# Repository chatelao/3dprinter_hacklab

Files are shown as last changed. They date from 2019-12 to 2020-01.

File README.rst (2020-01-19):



.. readme-header-marker-do-not-remove

Unser 3D Drucker im Hacklab Bern
################################

Anleitung zum Drucken
~~~~~~~~~~~~~~~~~~~~~

Der 3D Drucker im **Hacklab Bern** (https://www.meetup.com/de-DE/Bern-Silicon-Valley-HackLab-Tech-Group),
basiert auf dem `CL-260 <https://www.thingiverse.com/groups/cl-260/things>`_ 
open-source `Model <https://www.thingiverse.com/minicooper/collections/cl-260>`_.
Er wird abwechslungsweise von Mitgliedern genutzt und verbessert.

Slicer Software für PC/Mac
==========================

Für das Erstellen der Druckbefehle aus den (.stl) 3D-Modellen wird zwingend ein *Slicer* Programm
benötigt. Der grosse Klassiker ist *Cura*, die Alternativen wie *Prusa-Slicer* funktionieren sehr
ähnlich:

+-------------------------------------------------------+---------------+-------------------+
|                       Software                        |     Zweck     | Chocolately Paket |
+=======================================================+===============+===================+
| Cura                                                  | Slicer        | cura-new          |
+-------------------------------------------------------+---------------+-------------------+
| `Prusa Slicer <https://www.prusa3d.com/prusaslicer>`_ | Slicer        | prusaslicer       |
+-------------------------------------------------------+---------------+-------------------+

Der Slicer muss gewisse Details des Druckers kennen, damit er ihn gut ansteuern kann. Anbei 
einige bewährte, wesentliche Einstellungen:

+--------------------+----------------------------------+
|    Einstellung     |         Empfohlener Wert         |
+====================+==================================+
| Drucker Art        | FFF (Fused Filament Fabrication) |
+--------------------+----------------------------------+
| Druckauflösung     | 0.15mm                           |
+--------------------+----------------------------------+
| Retraction         | **5mm**                          |
+--------------------+----------------------------------+
| PLA Druckkopf      | 210°C (erste Schicht) / 200°C    |
+--------------------+----------------------------------+
| PLA Heizbett       | 55°C (erste Schicht) / 50°C      |
+--------------------+----------------------------------+

Software zur Fernsteuerung
==========================

Die Steuerung und Statuskontrolle des Druckers geht viel einfacher mit `OctoPrint <https://octoprint.org/download/>`_  auf einem RaspberryPi. Damit lassen sich Durckdateien bequem hochladen und der Status jederzeit abfragen. Noch mehr Komfort bieten Plug-Ins wie:

- `Telegram Integration <https://github.com/fabianonline/OctoPrint-Telegram>`_
- `Fortschrittsanzeige auf dem Drucker <https://github.com/OllisGit/OctoPrint-DisplayLayerProgress>`_

Filamente
=========

Kein Druck ohne Filamente, diese können hier bezogen werden:

- Im FabLab Bern: https://www.objektweberei.ch
- Online u.a. bei 3D-Jake: https://www.3djake.ch/de-CH/filament/pla-filament

Anleitung zum Warten
~~~~~~~~~~~~~~~~~~~~

Bed leveling
============

- Autohome
- Z-Axes senken
- Differenz an am Z-Stopp nachschrauen
- Alle Vier Ecken nachprüfen

Nozzle reinigen
===============

- https://www.youtube.com/watch?v=g8uvh6kvr54
- **Cold pull** das Hotend auf 120°C anwärmen und laufend ziehen, bis das Verstopfte herauskommen.

Wartungssoftware
================

Zur Wartung des Druckers hilft *Pronterface*, es stellt die technischeren Schnittstellen, wie
das serielle Terminal zur direkten Kommunikation mit dem Drucker und bequeme Kontrolleknöpfe
zum Bewegen der Achsen zur Verfügung.

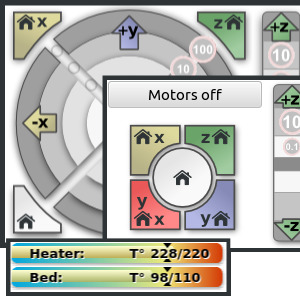
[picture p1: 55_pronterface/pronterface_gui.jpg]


+-------------------------------------------------------+---------------+-------------------+
|                       Software                        |     Zweck     | Chocolately Paket |
+=======================================================+===============+===================+
| `Pronterface <https://www.pronterface.com/>`_         | Fernsteuerung | printrun          |
+-------------------------------------------------------+---------------+-------------------+

Hardware & Werkzeug
===================

- Akkupunkturnadeln
- 2.5mm Imbusschlüssel
- 7mm Innen Sechskantschlüssel
- Messingbürste
- Flachzange
- Seitenschneider
- 1.3mm Imbusschlüssel
- M3 Schrauben und Muttern
- 5er Gabelschlüssel
- Isopropanol
- Haushaltspapier
- Schieblehre
- Kaptontape

Fehlersuche
===========

Die Fehlersuche am Drucker ist mühsam, allerdings bietet Pursa ein Handbuch
zum Erkennen der gängigsten Fehler:

- https://www.prusa3d.com/print-quality-troubleshooting/

Dazu hat auch der 3D-Andi ein hervorragendes Video mit vielen Fehlerquellen und -lösungen gedreht:

- https://www.youtube.com/watch?v=WL3T_ijUUs8

Düse montieren
==============

Bei der Montage der Düse ist sicherzustellen, dass die Düse kalt nur 0.7mm vor dem Limit angezogen ist.
In warmem Zustand kann die Düse zusätzlich nach ajustiert werden.

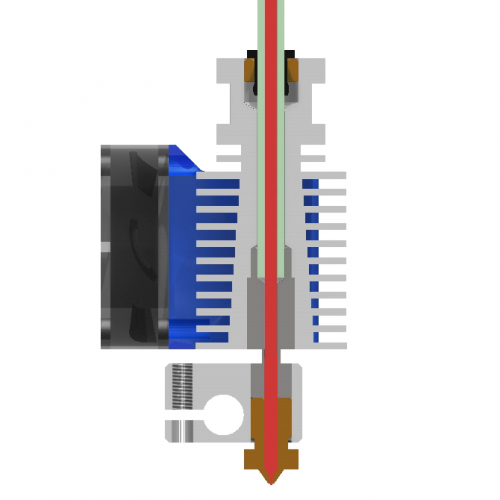
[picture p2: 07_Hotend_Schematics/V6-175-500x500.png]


- https://youtu.be/OzRAVkXjw3I

Kalibrationsmuster
==================

Zur Prüfung der Ausrichtung des Heizbetts eignen sich dieses speziellen Quadratmuster. Es erlaubt die Prüfung
der Druckhöhe und der Distanz zwischen Hotend und Heizbetts.

- Video: https://youtu.be/RZRY6kunAvs
- Quelle: https://www.thingiverse.com/thing:2789086
- STL: `calibration_patterns <https://github.com/chatelao/3dprinter_hacklab/tree/master/calibration_patterns>`_

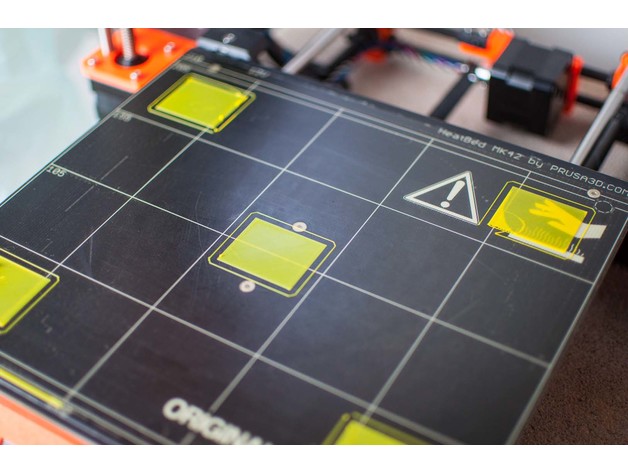
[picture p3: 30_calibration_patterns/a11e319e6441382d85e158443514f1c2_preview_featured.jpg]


Weitere Kalibrierungsmuster:
- https://www.youtube.com/watch?v=kgCjDy_IgXg

Support Forum
=============

- https://www.3d-druck-community.de/

Aktueller Aufbau
################

Die Mitglieder verbessern den Aufbau des Druckers laufend. Aktuell setzt er sich aus folgenden Bestandteilen zusammen:

+---------------------------------------------------------+--------------------------------------------------------------------------------------------------------------+
|                     Funktionalität                      |                                                    Verwendete Lösung                                         |
+=========================================================+==============================================================================================================+
| Firmware                                                | `Marlin 2.0.x <https://github.com/MarlinFirmware/Marlin>`_                                                   |
+---------------------------------------------------------+--------------------------------------------------------------------------------------------------------------+
| Mikrocontroller                                         | `Arduino Mega 2560 <https://www.3dware.ch/Iduino-MEGA2560-De.htm>`_                                          |
+---------------------------------------------------------+--------------------------------------------------------------------------------------------------------------+
| Leistungselektronik Shield                              | `RepRap-Arduino-Mega-Pololu-Shield (RAMPS) 1.4 <https://reprap.org/wiki/RAMPS_1.4>`_                         |
+---------------------------------------------------------+--------------------------------------------------------------------------------------------------------------+
| Verstärker Schrittmotoren                               | `A4988 Datasheet <https://www.allegromicro.com/~/media/Files/Datasheets/A4988-Datasheet.ashx>`_              |
+---------------------------------------------------------+--------------------------------------------------------------------------------------------------------------+
| Display Platine                                         | `RepRapdiscount smart controller 2004 LCD (RED) <https://reprap.org/wiki/RepRapDiscount_Smart_Controller>`_  |
+---------------------------------------------------------+--------------------------------------------------------------------------------------------------------------+
| Schrittmotoren                                          | NEMA ?                                                                                                       |
+---------------------------------------------------------+--------------------------------------------------------------------------------------------------------------+
| Zahnriemen                                              | 5mm breit, 2mm Zahnschritt                                                                                   |
+---------------------------------------------------------+--------------------------------------------------------------------------------------------------------------+
| Antriebsstangen                                         | 8mm Stahlstangen                                                                                             |
+---------------------------------------------------------+--------------------------------------------------------------------------------------------------------------+
| Lager der Antriebsstangen                               | 8 mm (innen) / 22 mm (aussen) / 7 mmm (Dicke) Standardlager                                                  |
+---------------------------------------------------------+--------------------------------------------------------------------------------------------------------------+
| Pulley                                                  | 20 Zähne, 8mm Innendurchmesser, mit M3 Imbusfixierung                                                        |
+---------------------------------------------------------+--------------------------------------------------------------------------------------------------------------+
| Heat Bed                                                |                                                                                                              |
+---------------------------------------------------------+--------------------------------------------------------------------------------------------------------------+
| Bowden Schlauch                                         | `2mm PTFE Tube <https://www.aliexpress.com/item/4000266365536.html>`_                                        |
+---------------------------------------------------------+--------------------------------------------------------------------------------------------------------------+
| Bowden Start (Motor, M5)                                | `PC4-M5 <https://www.aliexpress.com/item/4000182529332.html>`_                                               |
+---------------------------------------------------------+--------------------------------------------------------------------------------------------------------------+
| Bowden Ende (Heizkopf, R1/8)                            | `PC4-01 <https://www.aliexpress.com/item/4000182529332.html>`_                                               |
+---------------------------------------------------------+--------------------------------------------------------------------------------------------------------------+
| Hot End                                                 | Hotend: e3d v6                                                                                               |
+---------------------------------------------------------+--------------------------------------------------------------------------------------------------------------+
| Nozzle                                                  | 0.4mm                                                                                                        |
+---------------------------------------------------------+--------------------------------------------------------------------------------------------------------------+
| `3D Teile <https://www.thingiverse.com/thing:1800495>`_ | Gedruckte Teile                                                                                              |
+---------------------------------------------------------+--------------------------------------------------------------------------------------------------------------+
| Stromversorgung                                         | Schaltnetzteil 12V 20A ohne aktive Kühlung                                                                   |
+---------------------------------------------------------+--------------------------------------------------------------------------------------------------------------+
| Medium                                                  | SD-Karte, regulärer Grösse                                                                                   |
+---------------------------------------------------------+--------------------------------------------------------------------------------------------------------------+
| Datenkabel                                              | USB-Kabel mit Standard-B Stecker den Mikrocontroller                                                         |
+---------------------------------------------------------+--------------------------------------------------------------------------------------------------------------+

Marlin Konfiguration
~~~~~~~~~~~~~~~~~~~~

Mit der Pronterface_ Software kann der Drucker über `gCode Befehle <http://marlinfw.org/docs/gcode/M115.html>`_ oder das GUI mit der seriellen Schnittstelle ferngesteuert und untersucht werden:

M115 - Firmware Informations
============================

::

   >>> M115
   SENDING:M115
   FIRMWARE_NAME:Marlin 2.0.x (GitHub)
   SOURCE_CODE_URL:https://github.com/MarlinFirmware/Marlin
   PROTOCOL_VERSION:1.0
   MACHINE_TYPE:Hacklab CL260 
   EXTRUDER_COUNT:1 
   UUID:b01ac89d-d7b3-43ec-8f82-dfb65c785486
   
   Cap:SERIAL_XON_XOFF:0
   Cap:BINARY_FILE_TRANSFER:0
   Cap:EEPROM:0
   Cap:VOLUMETRIC:1
   Cap:AUTOREPORT_TEMP:1
   Cap:PROGRESS:0
   Cap:PRINT_JOB:1
   Cap:AUTOLEVEL:0
   Cap:Z_PROBE:0
   Cap:LEVELING_DATA:0
   Cap:BUILD_PERCENT:0
   Cap:SOFTWARE_POWER:0
   Cap:TOGGLE_LIGHTS:0
   Cap:CASE_LIGHT_BRIGHTNESS:0
   Cap:EMERGENCY_PARSER:0
   Cap:PROMPT_SUPPORT:0
   Cap:AUTOREPORT_SD_STATUS:0

M503 - Report Settings (Marlin 2.0.x)
=====================================

+--------------------------------+----------------------------------------------------+--------------+
|          Einstellung           | gCode                                              | Marlin 2.0.x |
+================================+====================================================+==============+
| Units in mm (mm)               | `G21 <http://marlinfw.org/docs/gcode/G021.html>`_  |              |
+--------------------------------+----------------------------------------------------+--------------+
| Filament diameter              | `M200 <http://marlinfw.org/docs/gcode/M200.html>`_ | D1.75        |
+--------------------------------+----------------------------------------------------+--------------+
| Steps per unit                 | `M92 <http://marlinfw.org/docs/gcode/M92.html>`_   | X80.00       |
|                                |                                                    +--------------+
|                                |                                                    | Y80.00       |
|                                |                                                    +--------------+
|                                |                                                    | Z1600.00     |
|                                |                                                    +--------------+
|                                |                                                    | E161.00      |
+--------------------------------+----------------------------------------------------+--------------+
| Max. Speed (mm/s)              | `M203 <http://marlinfw.org/docs/gcode/M203.html>`_ | X300.00      |
|                                |                                                    +--------------+
|                                |                                                    | Y300.00      |
|                                |                                                    +--------------+
|                                |                                                    | Z5.00        |
|                                |                                                    +--------------+
|                                |                                                    | E45.00       |
+--------------------------------+----------------------------------------------------+--------------+
| Max. Acceleration (mm/s2)      | `M201 <http://marlinfw.org/docs/gcode/M201.html>`_ | X9000        |
|                                |                                                    +--------------+
|                                |                                                    | Y9000        |
|                                |                                                    +--------------+
|                                |                                                    | Z100         |
|                                |                                                    +--------------+
|                                |                                                    | E10000       |
+--------------------------------+----------------------------------------------------+--------------+
| S=Acceleration                 | `M204 <http://marlinfw.org/docs/gcode/M204.html>`_ |              |
+--------------------------------+                                                    +--------------+
| P=Print Acceleration (mm/s2)   |                                                    | P3000.00     |
+--------------------------------+                                                    +--------------+
| R=Retract Acceleration (mm/s2) |                                                    | R3000.00     |
+--------------------------------+                                                    +--------------+
| T=Retract Acceleration (mm/s2) |                                                    |              |
+--------------------------------+                                                    +--------------+
| T=Travel Acceleration (mm/s2)  |                                                    | T3000.00     |
+--------------------------------+----------------------------------------------------+--------------+
| B=minimum segment time (ms)    | `M205 <http://marlinfw.org/docs/gcode/M205.html>`_ | B20000       |
+--------------------------------+                                                    +--------------+
| S=Min feedrate (mm/s)          |                                                    | S0.00        |
+--------------------------------+                                                    +--------------+
| T=Min travel feedrate (mm/s)   |                                                    | T0.00        |
+--------------------------------+                                                    +--------------+
| J=Junc_dev                     |                                                    | J0.01        |
+--------------------------------+----------------------------------------------------+--------------+
| Home offset (mm)               | `M206 <http://marlinfw.org/docs/gcode/M206.html>`_ | X0.00        |
|                                |                                                    | Y0.00        |
|                                |                                                    | Z0.00        |
+--------------------------------+----------------------------------------------------+--------------+
| Hotend PID settings            | `M301 <http://marlinfw.org/docs/gcode/M301.html>`_ | P22.20       |
|                                |                                                    +--------------+
|                                |                                                    | I1.08        |
|                                |                                                    +--------------+
|                                |                                                    | D114.00      |
+--------------------------------+----------------------------------------------------+--------------+

Der RepRap Shield
~~~~~~~~~~~~~~~~~

Das **RepRap Arduino Mega Pololu Shield** dient als Plattform zur Anbindung
aller weiteren Eletronik am System:

1. Dem *Arduino Mega* als Microkontroller
2. Den Schrittmotoren, ihren Reglern und Endsensoren
3. Dem Heizkopf und -bett, sowie ihren jeweiligen Messfühlern
4. Dem LCD-Display und Drehtaster mit SD-Kartenleser
5. Den Lüftern für den Heizkopf und das Material
6. etc.

Die Stecker und Verkabelungen
=============================

RAMPS 1.4 wiring schematics

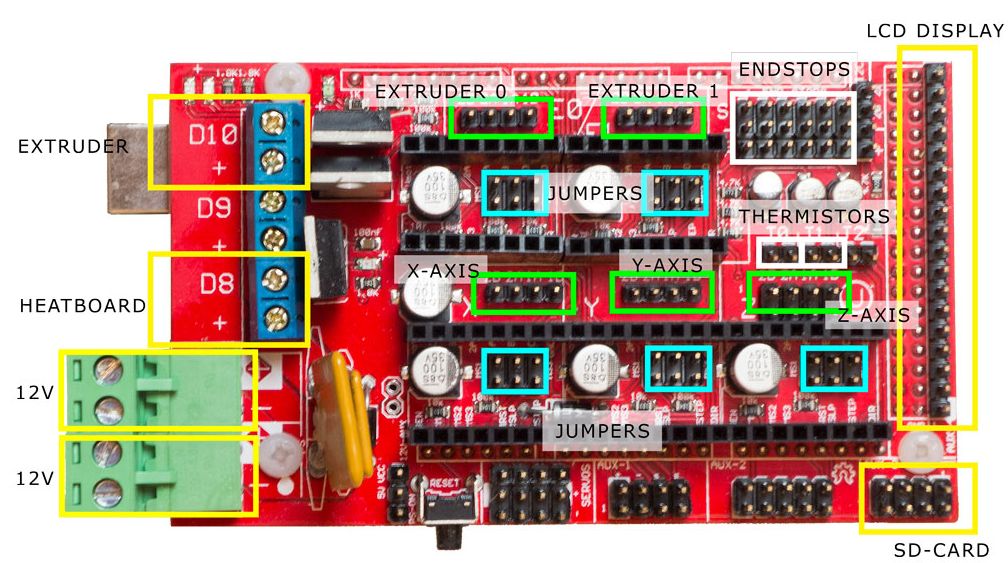
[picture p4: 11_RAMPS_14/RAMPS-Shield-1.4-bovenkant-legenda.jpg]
RAMPS 1.4 photo with pinout legend


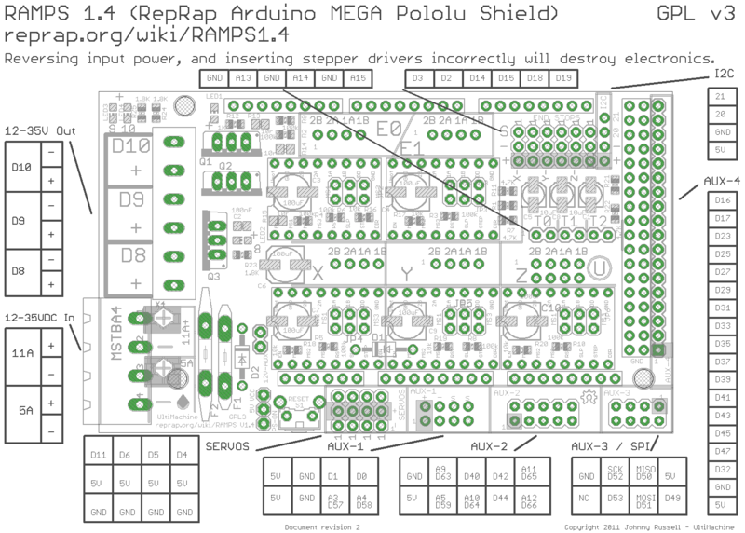
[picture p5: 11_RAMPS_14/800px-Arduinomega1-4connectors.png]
RAMPS 1.4 pinouts schematics


Das elektronische Schema
========================

RAMPS 1.4 electronic schematics


Der LCD-Display mit Taster & SD-Kartenlesen
~~~~~~~~~~~~~~~~~~~~~~~~~~~~~~~~~~~~~~~~~~~

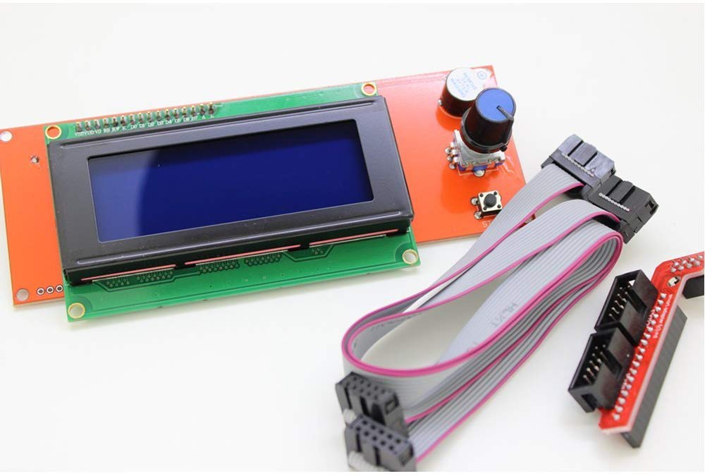
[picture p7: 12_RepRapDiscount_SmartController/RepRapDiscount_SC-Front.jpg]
RepRap-Discount SmartController frontside view


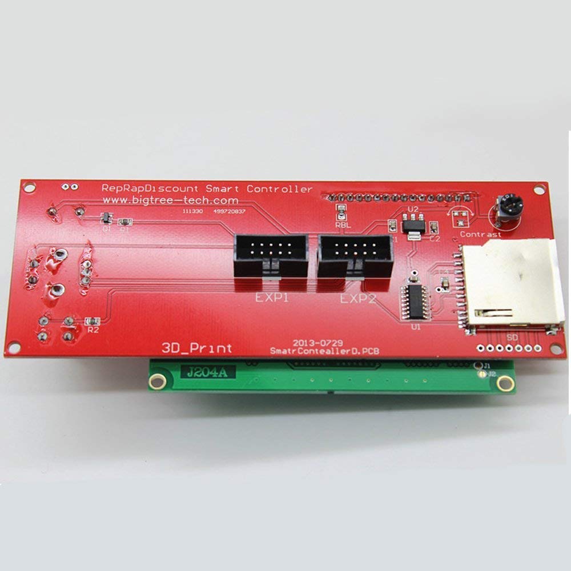
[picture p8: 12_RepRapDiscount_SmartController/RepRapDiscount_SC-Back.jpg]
RepRap-Discount SmartController backside view


Das elektronische Schema
========================

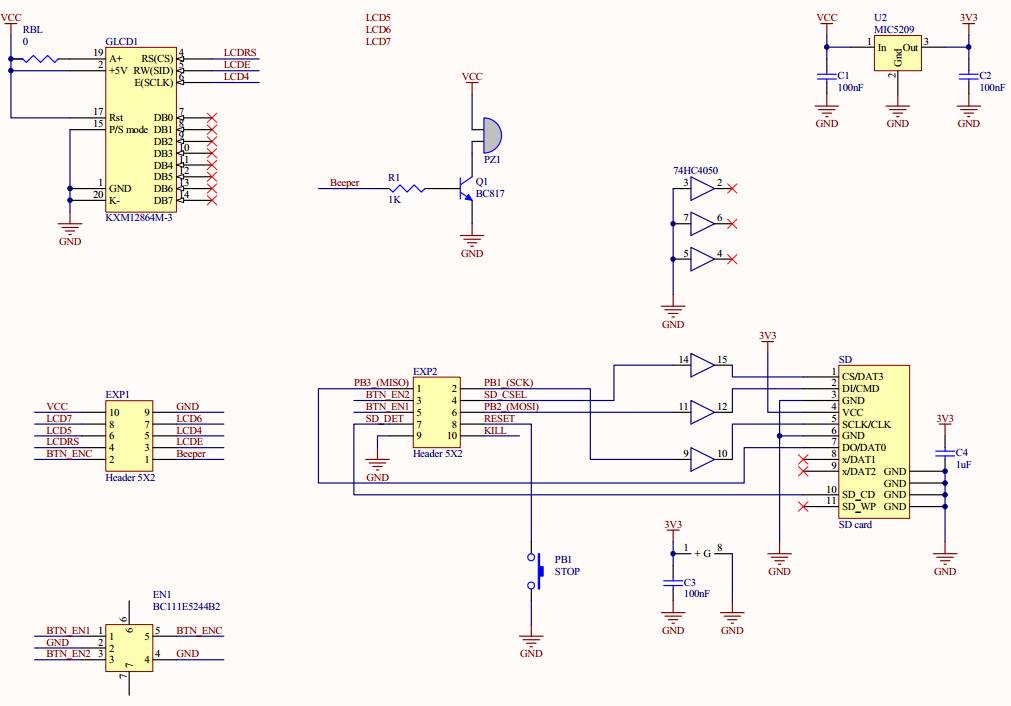
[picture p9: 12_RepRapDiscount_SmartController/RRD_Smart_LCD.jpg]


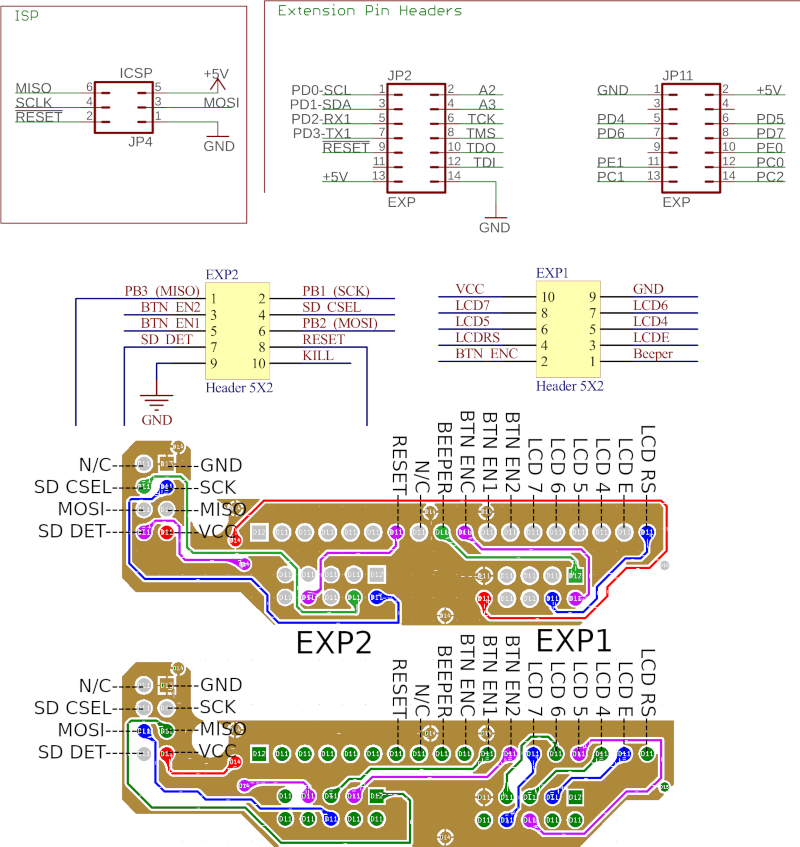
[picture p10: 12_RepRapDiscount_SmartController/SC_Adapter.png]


.. readme-next-page-do-not-remove

Geplante Verbesserungen
#######################

Erweiterungen
~~~~~~~~~~~~~

https://www.aliexpress.com/item/4000211772563.html

Filament runout sensor
======================

- Sensor casing: https://www.thingiverse.com/thing:1698397
- https://www.youtube.com/watch?v=gwHpXaj_6xE

RAMPS Ersatz mit 32-bit Prozessor
=================================

Die Kombination RAMPS1.4 und Arduino Mega ist der de-facto standard für 3D-Drucker.
Aktuell besteht nur ein geringer Bedarf diese Kombination abzulösen, da nur folgende
Schwächen bestehen:

#. Die Leistung der Heizausgänge ist auf 11A beschränkt (MKS v1.3: 20A)
#. Die Unterstützung eines TFT-Touchpanels ist mir nicht bekannt
#. Die Rechenleistung im 8-Bit Kontroller ist geriner als im 32-bit Modell

Ein  Kandidat wäre das BigTreeTech SKR V1.3
- https://www.aliexpress.com/item/32981807406.html

Induktive Abstandsensoren am Druckkopf
--------------------------------------

Das sogenannte "Bed Auto Leveling" ermöglicht es ein schiefes Druckbett zu kompensieren.
Es kann den Abstand zum Druckbett laufen und an allen Stellen ausmessen.

- https://youtu.be/G-TwWfUzXpc
- Sensor: https://de.aliexpress.com/item/32568347298.html

Verbesserte Halterung
- https://www.thingiverse.com/thing:2332037

Filamentreiniger
================

Auf den Filamenten haftet meist ein wenig Staub. Eine Reinigung vor dem Drucken reduziert die
Verunreinigung am Druckkopf.

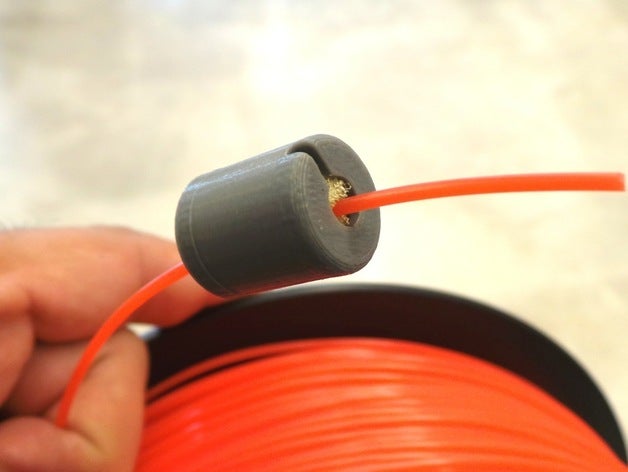
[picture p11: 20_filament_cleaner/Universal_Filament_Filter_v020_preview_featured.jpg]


Besseres Anzeigemodul
=====================

Anzeige - BIGTREETECH TFT24 V1.1
--------------------------------

- https://www.aliexpress.com/item/33047390457.html

Anzeige - LCD 12864
-------------------

Die LCD-Anzeige dient zur Steuerung des Druckers direkt am Gerät. Der SD-Card Leser
ist ebenfalls direkt in das Modul eingebaut. Dazu muss die 
`Marlin Konfiguration <http://marlinfw.org/docs/configuration/configuration.html#lcd-controller>`_
korrekt eingestellt werden.

Aktuell enthält der Drucker ein einfaches, sehr funktionales LCD 20x2 Zeichen Display.
Ein grösseres Display könnte die gleichen Daten etwas komfortabler darstellen. Eine
Option ist ein $8
`LCD 12864 Module from Aliexpress <https://www.aliexpress.com/item/1000007365397.html>`_.

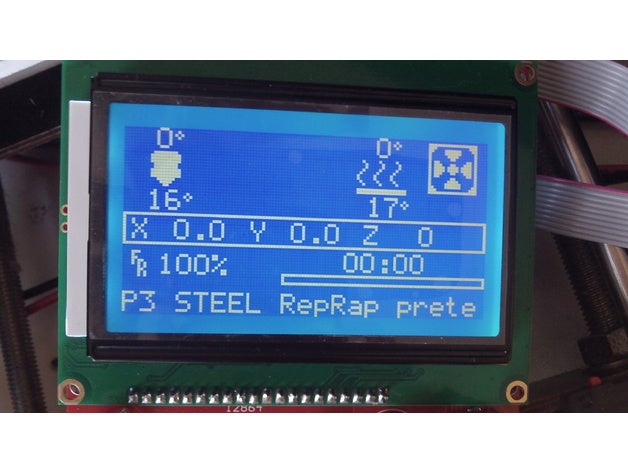
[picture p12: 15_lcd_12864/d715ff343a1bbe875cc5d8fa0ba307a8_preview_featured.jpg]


Ein dazu passendes Gehäuse fand sich auf `Thingiverse <https://www.thingiverse.com/thing:2813298>`_,
oder hier im `Verzeichnis <https://github.com/chatelao/3dprinter_hacklab/blob/master/lcd_12864/Top_Shell.stl>`_.

Durchgeführte Verbesserungen
~~~~~~~~~~~~~~~~~~~~~~~~~~~~

Neue TMC2130 Treiber für Schrittmotoren
=======================================

Die aktuellen Treiberchips der Schrittmotoren sind klassische Pololu A4988.
Diese Trieber steuern den Drucker korrekt, aber können keine Schrittverluste
erkennen oder korrigieren. Die Motoren sind bei der Ansteuerung auch relativ laut.

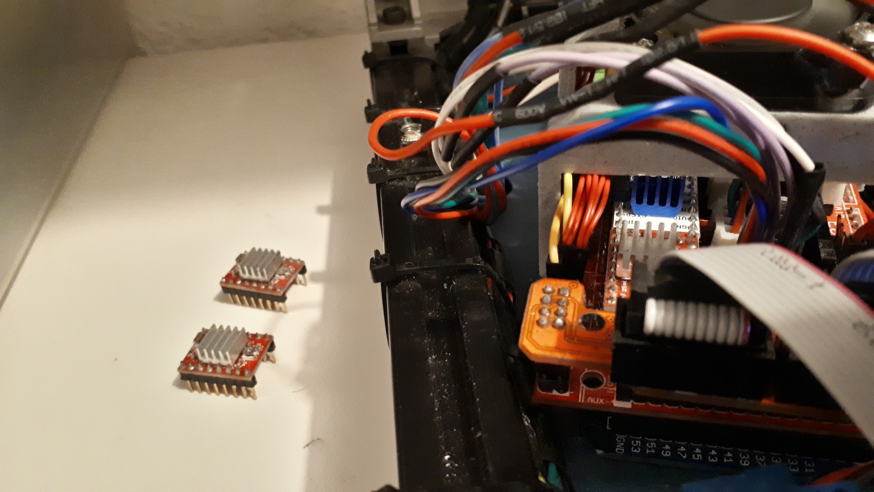
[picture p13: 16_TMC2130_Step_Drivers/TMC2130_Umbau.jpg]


Die Alternative dazu sind die TMC2130 der Firma Trinamic. Sie erlauben es, 
Blockierungen und damit Schrittverluste zu erkenne.

- Anleitung zum Erhalten der LCD und SD-Karte (Chris Riley): https://www.youtube.com/watch?v=kMICfCa6bHk

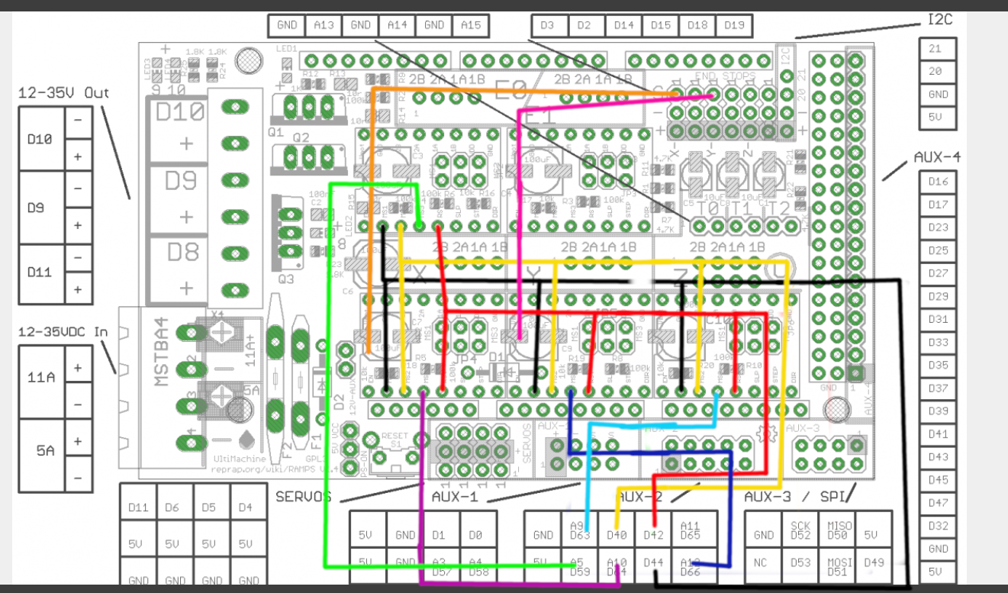
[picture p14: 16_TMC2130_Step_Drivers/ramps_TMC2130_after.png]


- Alterativ, aber unvollständig (Tom Sandladerer): https://www.youtube.com/watch?v=sPvTB3irCxQ&t=728s

Neue Firmware
=============

Die aktuelle Firmware funktioniert wie gewünscht, ist allerdings nicht auf dem allerneusten Stand.
Allfällige Verbesserungen in der Logik und Sicherheit der letzten Jahre fehlen noch und der
Sourcecode ist aktuell nicht bekannt, allerdings ergibt die "M115" Abfrage ein Marlin V1.

Daher wären eine Aktualisierung in Erwägungen zu ziehen:

#. Die bestehende Firmware durch Ausbau des Arduino Mega Boards sichern.
#. Ein neues Arduino Mega Board (`$9 Aliexpress <https://www.aliexpress.com/item/32719027443.html>`_) für die Versuche mit der neuen Firmware einbauen.
#. Neue Firmware  `Marlin 2.0 <https://github.com/MarlinFirmware/Marlin>`_ oder Repetier_ herunterladen.
#. Die Software für den Drucker konfigurieren (siehe HW-Konfiguration).
#. Die Software installieren und mit Pronterface_ testen.

Hilfestellungen in der Fehlersuche der neuen Konfiguration:

- https://www.youtube.com/watch?v=0pt_b2ZizQM
- https://www.youtube.com/watch?v=lAKyZd63_ns (2016: https://www.youtube.com/watch?v=3gwWVFtdg-4)

Abfrage der Endabschalter
--------------------------

Mit der gCode Befehl M119 kann der aktuelle Zustand der Endabschalter ausgelesen werden.
Die Abfrage zeigt bei unserer Elektronik ausgelöste Stopps im offenen Zustand.
Ein anschliessend testweise ausgelöster Z-Entstopp wird als offen angezeigt, der Wert wird
also fehlerfrei ausgelesen und ist nur invertiert:

::

   Reporting endstop status
   x_min: TRIGGERED
   y_min: TRIGGERED
   z_min: open

Zur Korrektur muss die Konfiguration angepasst werden. Die xxx_MIN_ENDSTOP_INVERTING Werte sind
normalerweise "false" und müssen auf "true" umgestellt werden:

Bessere Z-Axis Distanzeinhaltung
================================

Nur eine präzises Startdistanz zum Heizbett erlaubt präzise erste Schichten.

Verbesserte Stopp Schalter Führung
----------------------------------

Der End-Stops soll den Schalter wiederholbar zum gleichen Zeitpunkt auslösen. Der Würfel erlaubt
grössere Toleranzen zum Treffen des Schalters.

Quelle:

- https://www.thingiverse.com/thing:2851658
- STL: `z_axis_sensor_print <https://github.com/chatelao/3dprinter_hacklab/tree/master/z_axis_sensor_print>`_

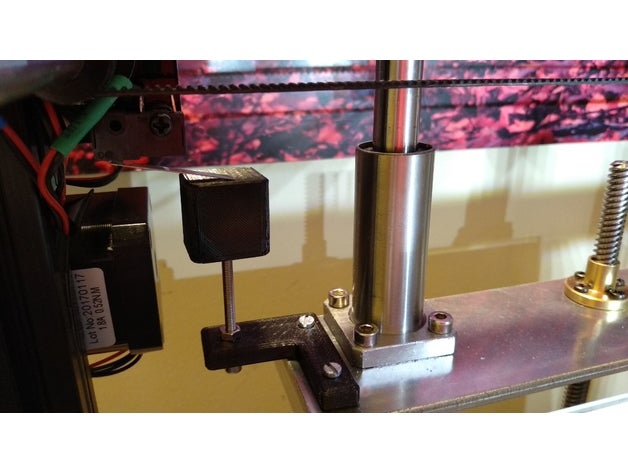
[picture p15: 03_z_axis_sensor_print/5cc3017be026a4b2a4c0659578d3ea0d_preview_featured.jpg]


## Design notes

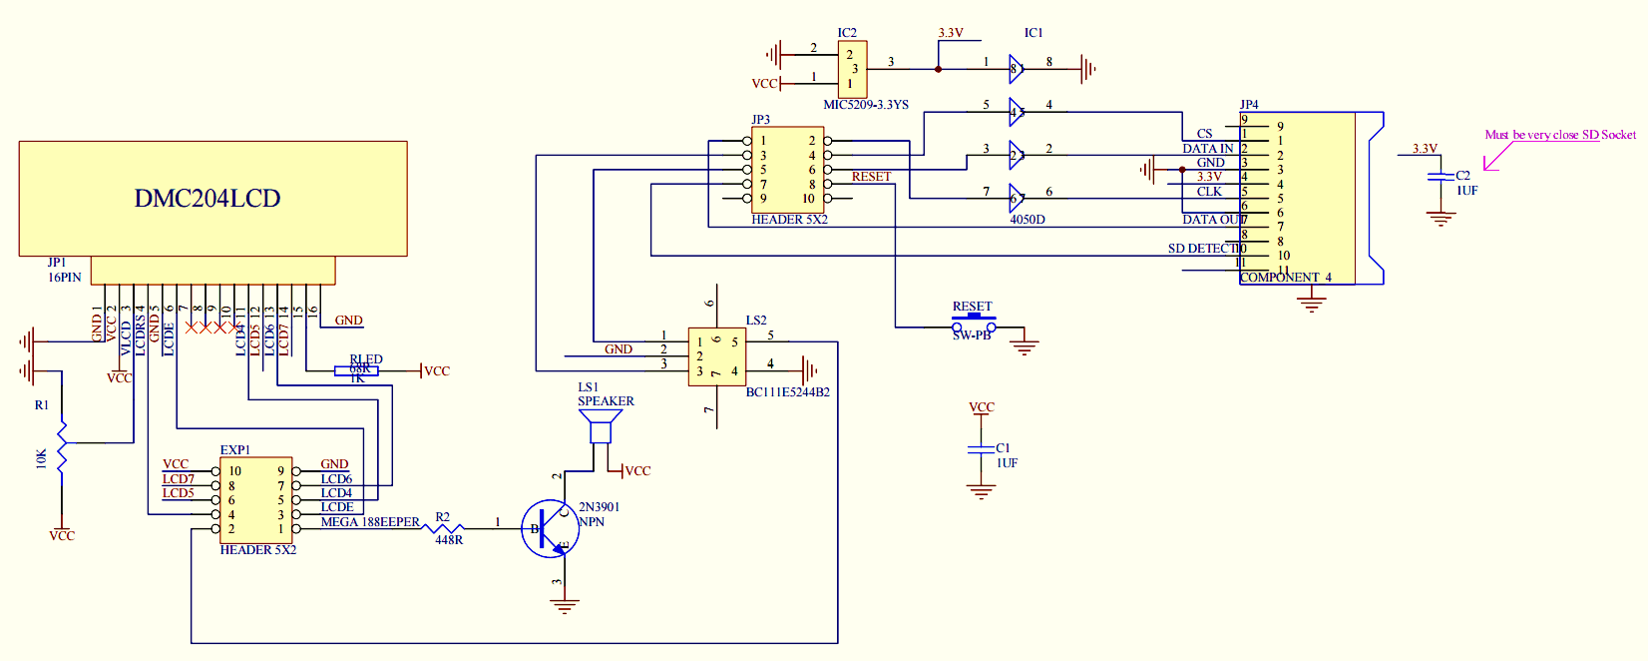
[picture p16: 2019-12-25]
12_RepRapDiscount_SmartController/SC_Schematics.png

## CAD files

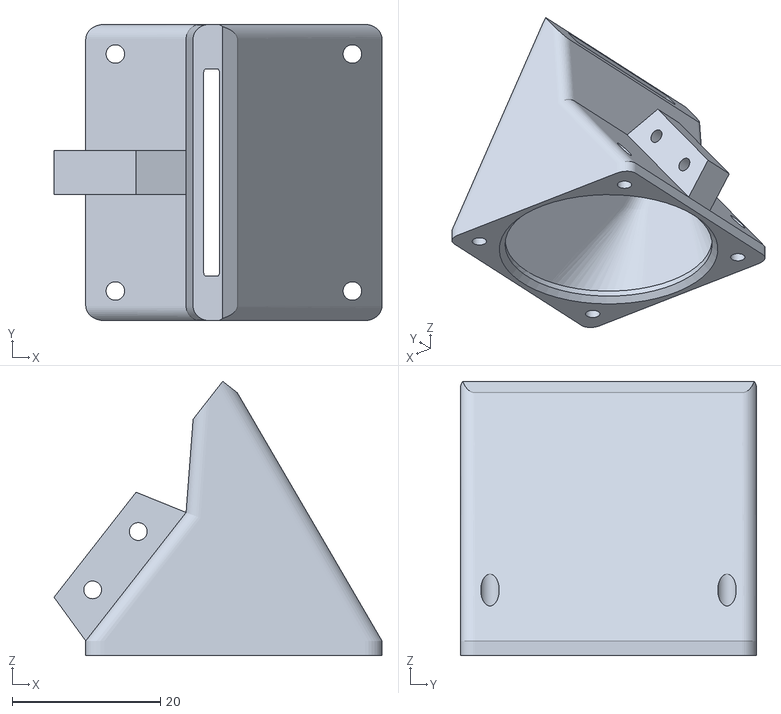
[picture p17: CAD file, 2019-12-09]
00_printer_parts/4010_fan.STL
44.3 x 40.0 x 37.0

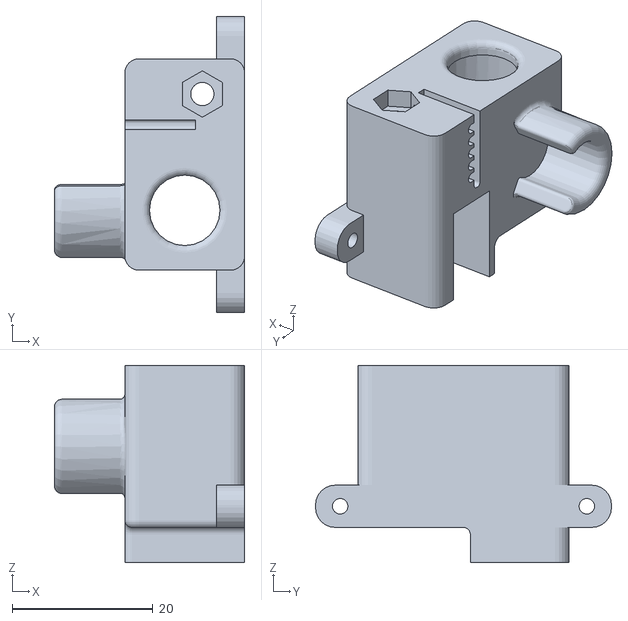
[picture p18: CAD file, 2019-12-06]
01_xy_belt_holder/XY-New_top.stl
27.0 x 42.0 x 28.0

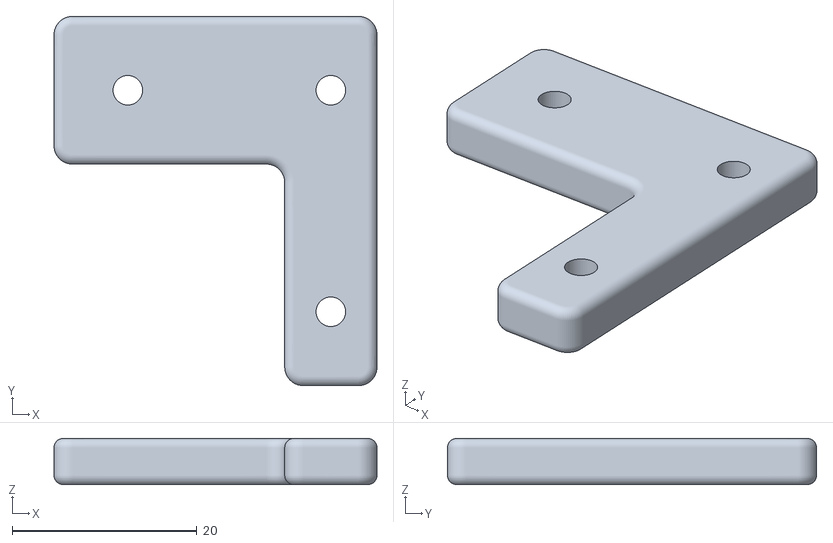
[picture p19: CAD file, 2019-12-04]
03_z_axis_sensor_print/endstop_base.stl
35.0 x 40.0 x 5.00

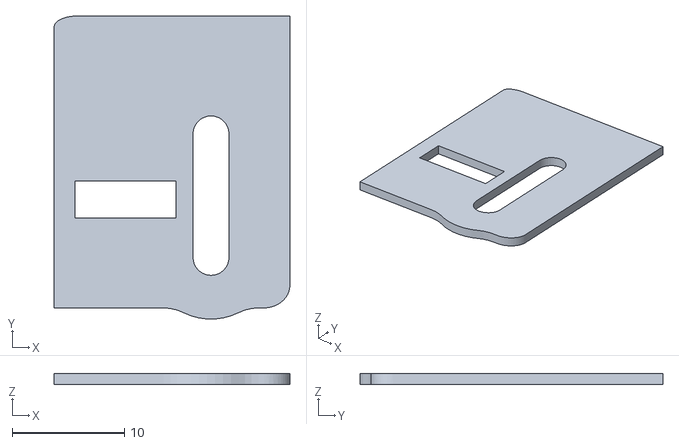
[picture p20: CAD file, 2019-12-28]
06_fan_upgrade/wedge_v4b.STL
21.0 x 27.0 x 1.00

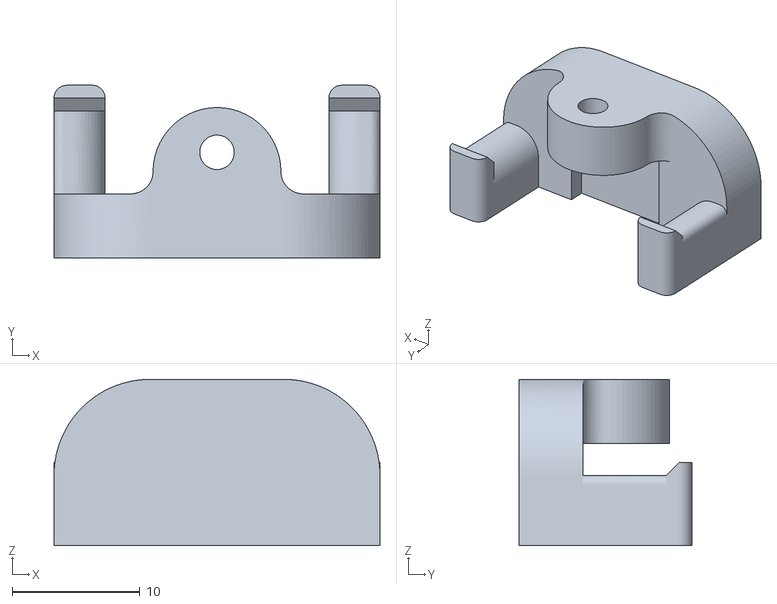
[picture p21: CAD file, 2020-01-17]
08_belt_tensioner/THICK_tensioner.stl
25.5 x 13.5 x 13.0

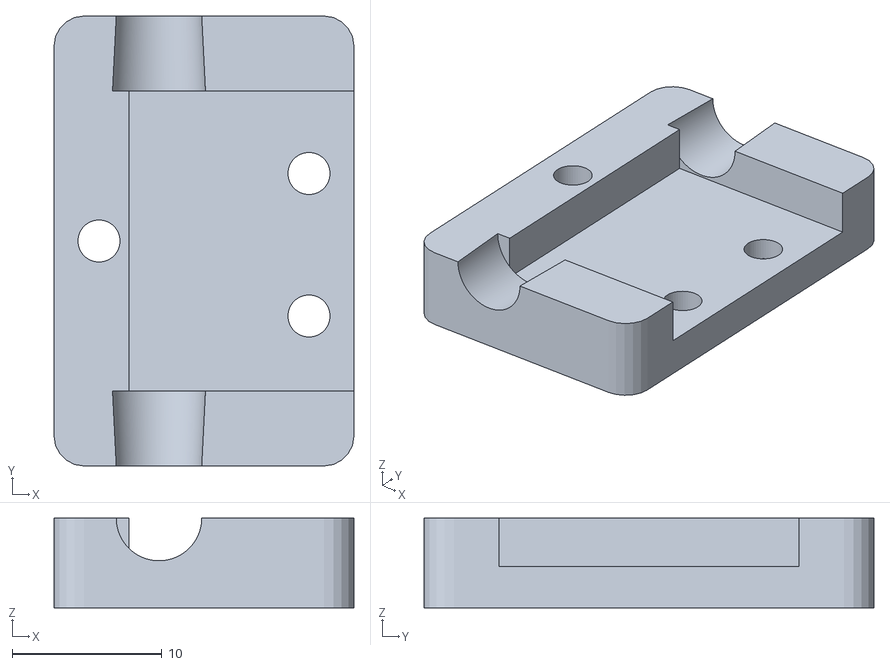
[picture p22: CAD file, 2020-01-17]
09_filament_runout_sensor/filamentSensorBottom300mm.stl
20.0 x 30.0 x 6.00

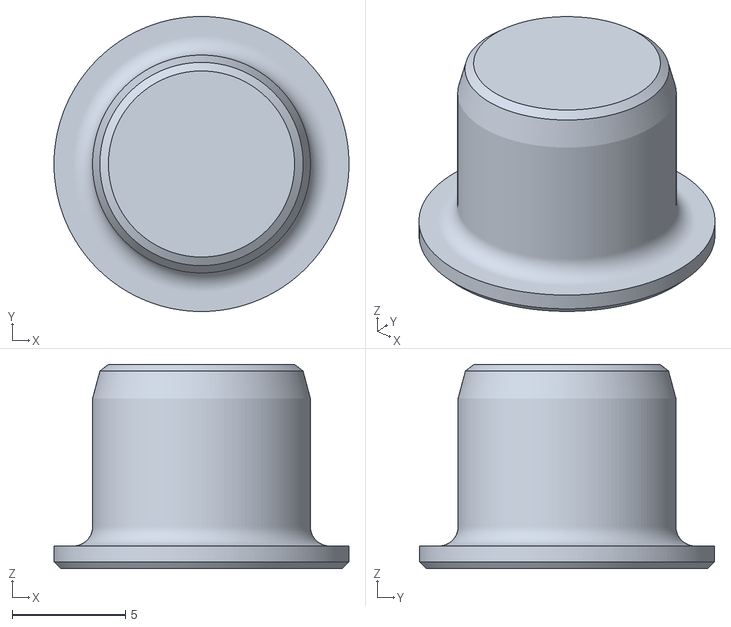
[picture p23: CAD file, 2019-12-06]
15_lcd_12864/Reset_Knob.stl
13.0 x 13.0 x 9.00

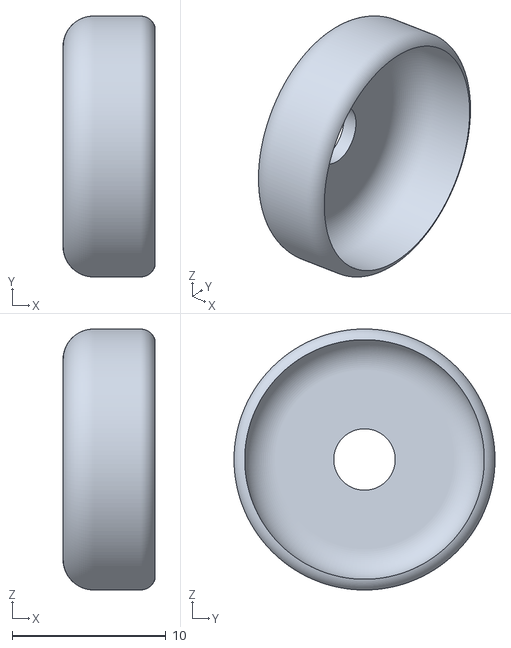
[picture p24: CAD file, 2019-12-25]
20_filament_cleaner/Filament-Filter_S-B_v4.stl
6.00 x 17.0 x 17.0

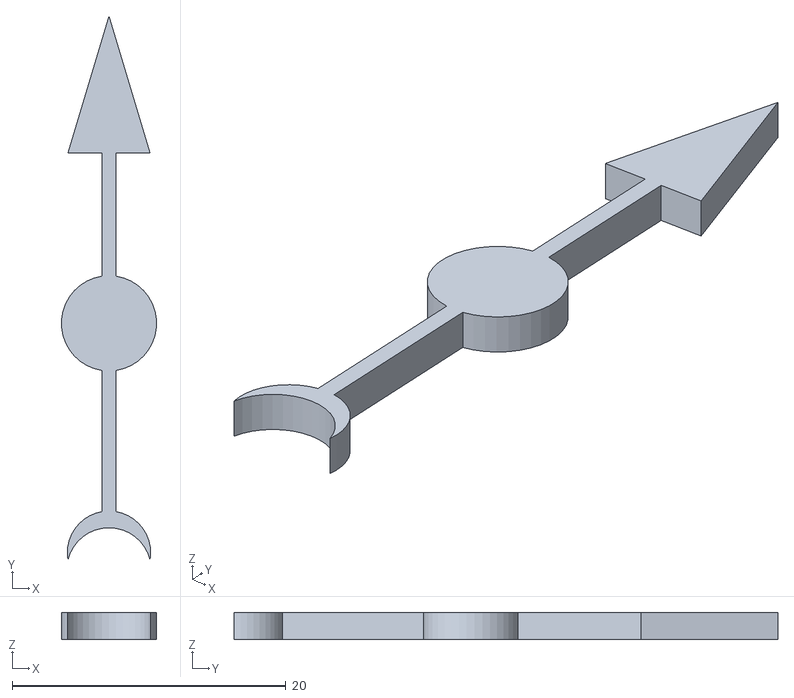
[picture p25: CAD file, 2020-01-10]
21_step_motor_idicator/step_motor_arrow.STL
6.94 x 39.8 x 2.00

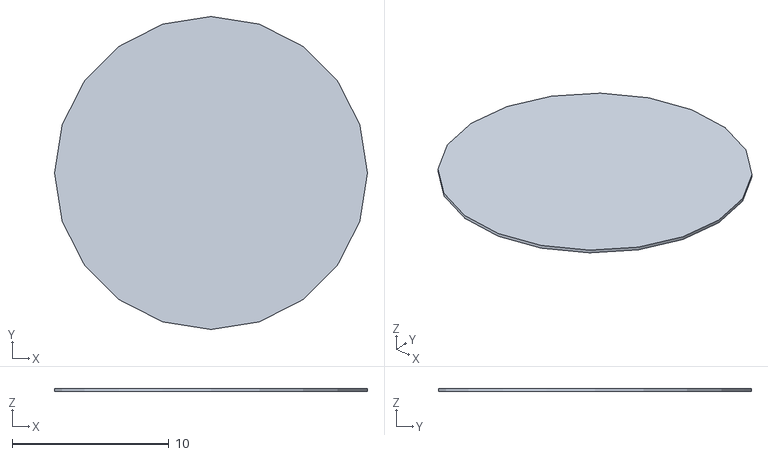
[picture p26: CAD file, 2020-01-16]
30_calibration_patterns/testbedcir1.stl
20.0 x 20.0 x 0.2

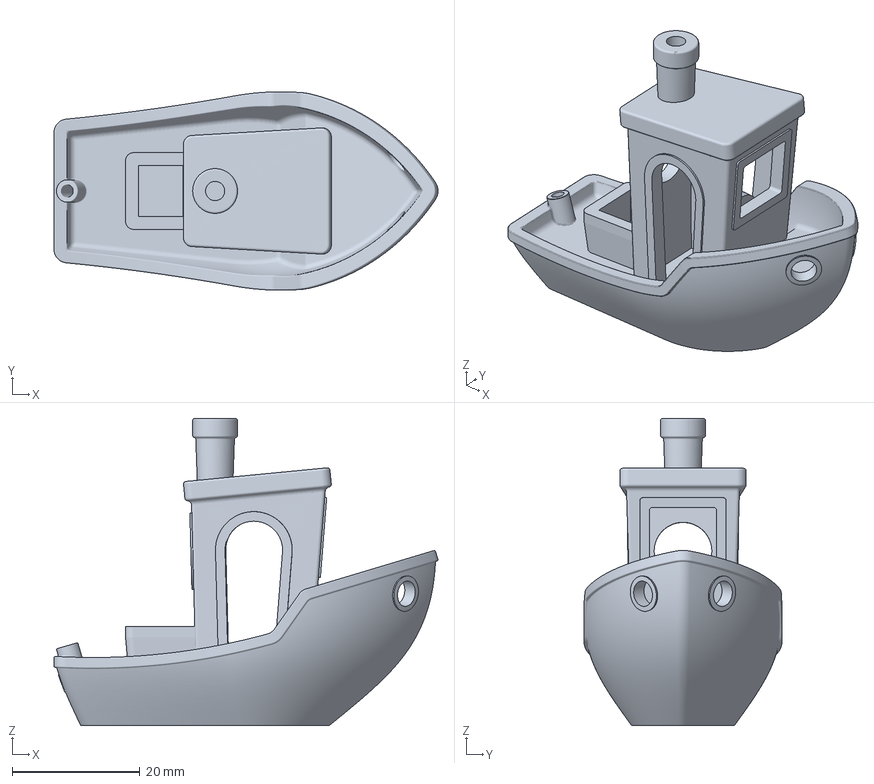
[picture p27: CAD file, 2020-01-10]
31_benchy_boat/3DBenchy.163.3mf
60.0 x 31.0 x 48.0 mm

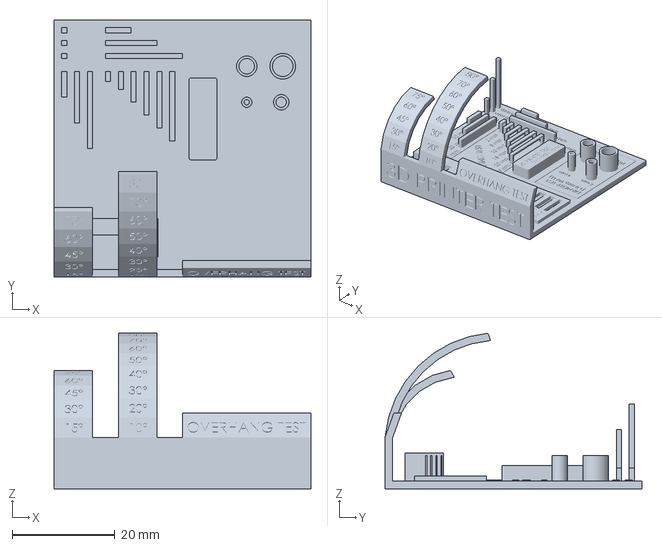
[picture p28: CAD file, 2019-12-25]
32_all_in_one_cube/3D_Printer_test_fixed_stl_3rd_gen.3mf
50.0 x 50.0 x 30.3 mm

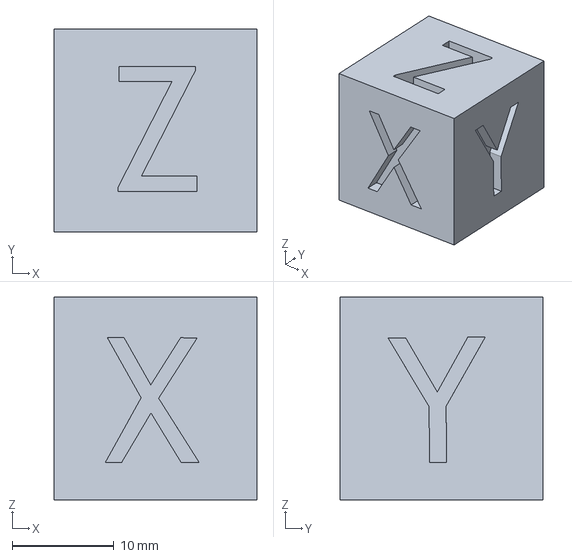
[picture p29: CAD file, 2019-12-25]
33_xyz_calibration_cube/xyzCalibration_cube.3mf
20.0 x 20.0 x 20.0 mm

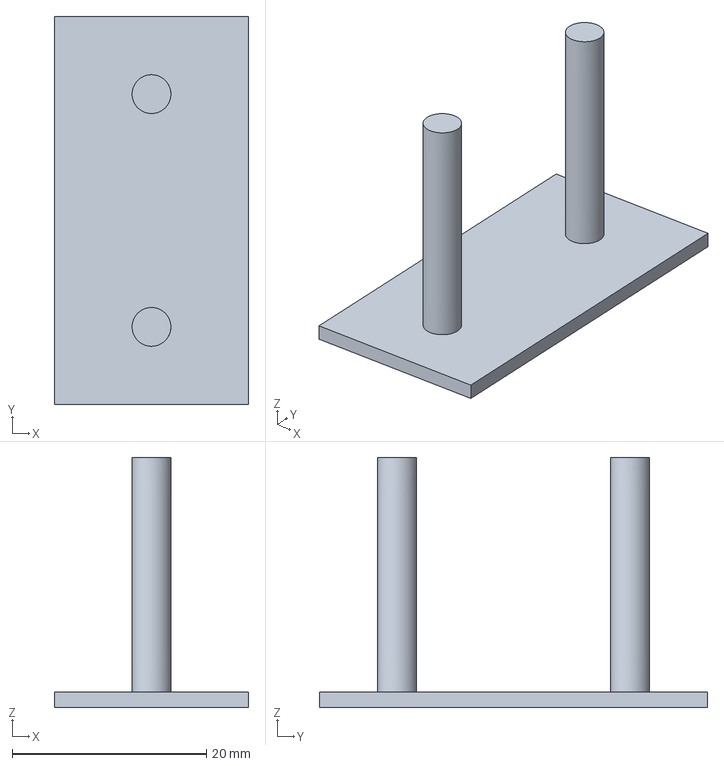
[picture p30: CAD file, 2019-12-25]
34_string_retracton_test/Stringing_Test.3mf
20.0 x 40.0 x 25.8 mm

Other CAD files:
35_calibration_block/GH_small_test_block.STL
36_all_in_one_test_big/AIl_In_One_3D_printer_test_micro.3mf
00_printer_parts/Y_axle_seat_B.STL
01_xy_belt_holder/clamp.stl
00_printer_parts/3010_fan.STL
00_printer_parts/Axis_calibrator.STL
00_printer_parts/Blocks.STL
00_printer_parts/Carriage.STL
00_printer_parts/End_stop.STL
00_printer_parts/Mounting_plate.STL
00_printer_parts/UPS.STL
00_printer_parts/X_axle_seat.STL
00_printer_parts/Y_axle_seat_A.STL
00_printer_parts/Z_axle_seat.STL
00_printer_parts/Z_end_stop_A.STL
00_printer_parts/Z_end_stop_B.STL
00_printer_parts/extruder_A.stl
00_printer_parts/extruder_B.stl
01_xy_belt_holder/Filler.stl
01_xy_belt_holder/XY-New_bottom.stl
02_hotend_holder/170222_CL260Head-D11CompactFan40.stl
03_z_axis_sensor_print/endstop_head.stl
05_Upgrades_aller_Art/Druckkopf/170420_CL260Head-D11Compact.stl
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

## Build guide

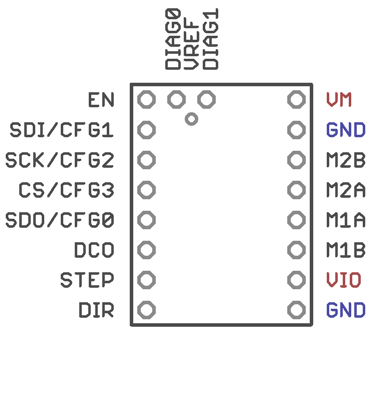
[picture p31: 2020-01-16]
16_TMC2130_Step_Drivers/tmc2130_v2.png

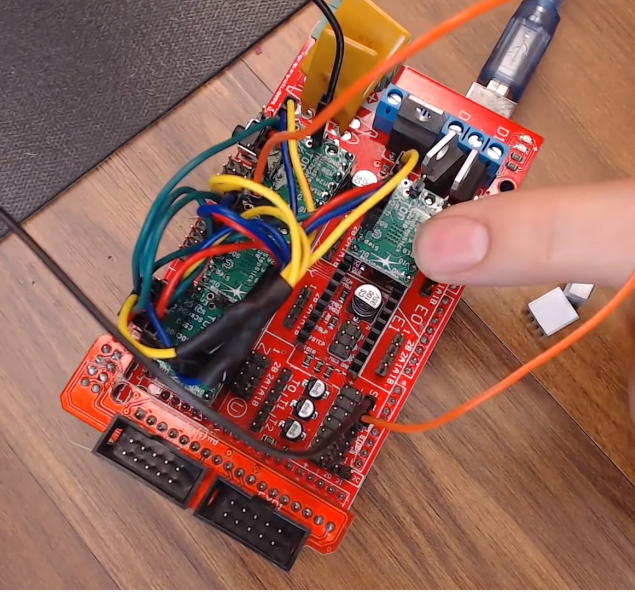
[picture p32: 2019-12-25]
16_TMC2130_Step_Drivers/Ramps_with_TMC2130_and_LCD.PNG

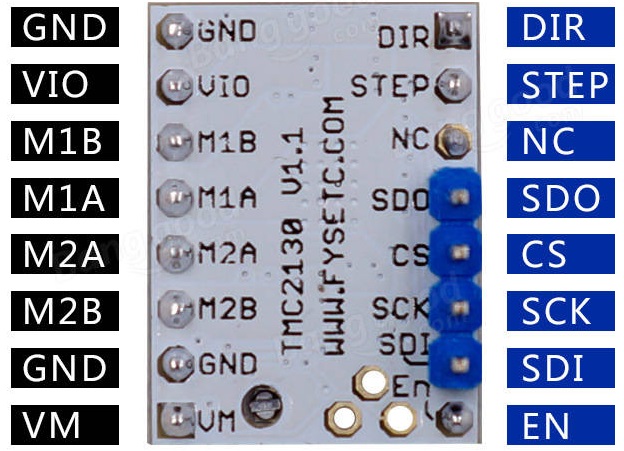
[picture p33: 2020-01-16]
16_TMC2130_Step_Drivers/TMC2130-5.jpg

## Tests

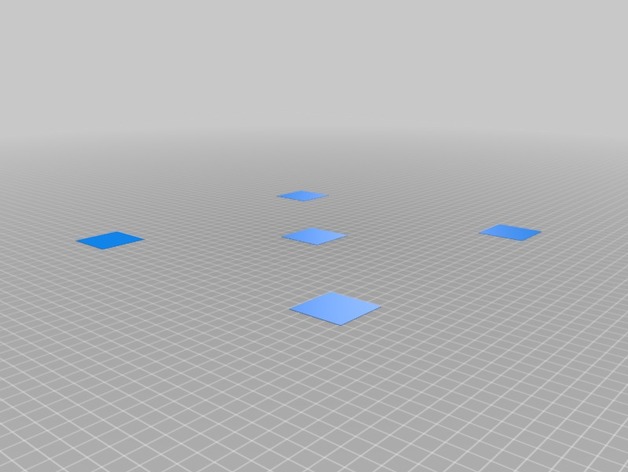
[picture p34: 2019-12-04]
30_calibration_patterns/df06908d54556435e9afe248215628a9_preview_featured.jpg

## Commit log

2019-12-04 Add - Endstop Z-Axis from Thingiverse
    [endstop_base.stl, endstop_head.stl]
2019-12-04 Add - Calibration pattern
    [20x20.stl]
2019-12-04 Chg - Calibration pattern path
    [20x20.stl]
2019-12-04 Add - Images
    [30x30.stl]
2019-12-05 Add - Filamentreiniger
    [Filament-Filter_L-A_v2.stl, Filament-Filter_S-A_v2.stl]
2019-12-05 Chg - Marlin 2.0 Link
2019-12-05 stl file für zusätzliche upgrade parts
    [170222_CL260Head-D11CompactFan40.stl, 170420_CL260Head-D15Compact-Igus.stl, Filler.stl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]
2019-12-06 Add - New display & holder
    [Bottom_Shell.stl, Display_Support_Frame.stl, Reset_Knob.stl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]
2019-12-07 Add - Current config from Marlin SW
2019-12-07 Add - CH340 Treiber für COM-Port auf Arduino Mega
2019-12-09 Chg - Regorganize subdirectories
    [170222_CL260Head-D11CompactFan40.stl, 170420_CL260Head-D15Compact-Igus.stl, 20x20.stl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]
2019-12-09 Add - 3D parts to replicate printer
    [3010_fan.STL, 4010_fan.STL, Axis_calibrator.STL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]
2019-12-10 Add - Current m503 from Marlin V1
2019-12-18 Chg - Remove Marlin V1 docus
2019-12-25 Add - RAMPS1.4 and TMC3120 more details
    [170117_Z_end_stop_B-02.3mf, 170117_Z_end_stop_B-02.stl, 170420_CL260Head-D11Compact.stl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]
2019-12-25 Chg - More accurate wiring diagramm
2019-12-25 Chg - More schematics
2019-12-28 Add - Fan designs
    [180102_ActiveDuct_NEW-01.stl, fan-duct_vent_tgt_v4b.3mf, fan-duct_vent_tgt_v4b.STL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]
2019-12-28 Add - TMC3120 schematics
2020-01-10 Chg - Benchies for each filament diameter
    [3DBenchy.163.3mf, 3DBenchy.175.3mf, 3DBenchy.3mf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]
2020-01-12 Tabelle und Links gefixt
2020-01-13 Add - 2n all in one test
    [AIl_In_One_3D_printer_test_micro.3mf, AIl_In_One_3D_printer_test_micro.stl]
2020-01-13 Chg - Rename some calibration objects
    [3D_Printer_test_fixed_stl_3rd_gen.3mf, 3D_Printer_test_fixed_stl_3rd_gen.STL, xyzCalibration_cube.3mf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]
2020-01-16 Chg - More details to the TMC2130
    [3D_Printer_test_fixed_stl_3rd_gen.3mf, 3D_Printer_test_fixed_stl_3rd_gen.STL, testbedcir1.stl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]
2020-01-17 Add - Bild des Umbaus
2020-01-17 Add - Riemen und Runout
    [170117_Z_end_stop_B-02.3mf, 170117_Z_end_stop_B-02.stl, 170420_CL260Head-D11Compact.stl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]
